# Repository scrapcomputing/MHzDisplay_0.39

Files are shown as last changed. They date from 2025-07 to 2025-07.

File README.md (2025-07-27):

# A Turbo LED MHz Display with 0.39" sized digits

A MHz Turbo LED display with 2x smaller 0.39" digits (12.8mm x 9.7mm x 7.0mm common cathode like the HD1107G).
These are smaller than the more common 0.56" display like the [TD-37S](https://github.com/scrapcomputing/MHzDisplayBlaster) or the [K568](https://github.com/scrapcomputing/MHzDisplay_K568).

I don't know the model number of the display that this is compatible with. If you do know please let me know!

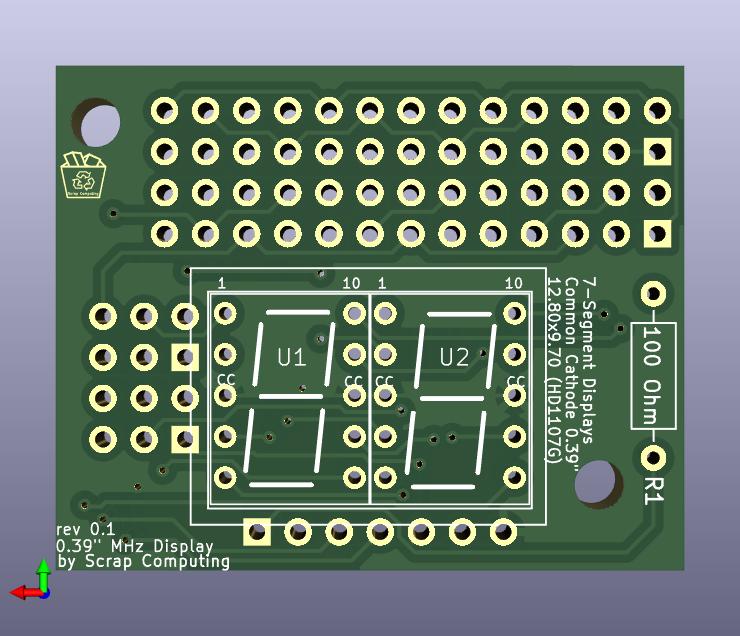
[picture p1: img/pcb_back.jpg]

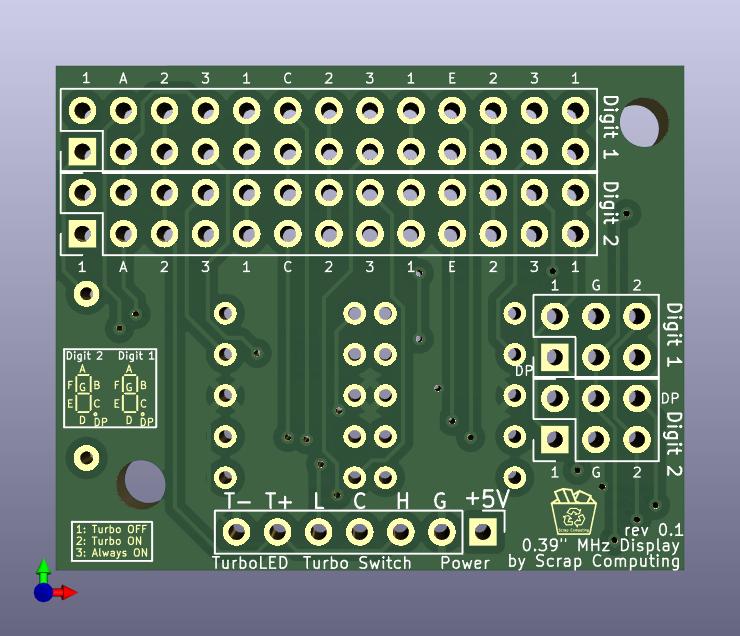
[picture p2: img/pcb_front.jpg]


As all similar displays, it is powered by 5V DC (pins +5V, G) and it can display a Turbo and a non-Turbo number, depending on the state of the Turbo switch (pins L C H, Low Common High).
It also drives the Turbo LED accordingly (pins T- and T+).

My case did not have an LED display that I could clone, so this is a design based on other common displays, like the [TD-37S](https://github.com/scrapcomputing/MHzDisplayBlaster).

Because of the limited space between the mounting holes, I had to the split the segment selection headers into two parts. The smaller headers are for segment G and the dot (DP).

# BOM

Gerber files are published in the [releases](https://github.com/scrapcomputing/MHzDisplay_0.39/releases).

Quantity | Item
---------|-------------------------------
2        | 2x13 2.54mm pitch pin headers
2        | 2x3  2.54mm pitch pin headers
1        | 1x7  2.54mm pitch pin header
1        | 100 Ohm 1/4 watt resistor (or smaller value for brighter display)
2        | Single-digit 7-segment Common-Cathode 0.39" displays that fit the PCB (display dimensions 9.7mm x 12.8mm x 7.0mm), like the HD1107G.
1        | [PCB](https://github.com/scrapcomputing/MHzDisplay_0.39/releases)

# Schematic



# Photos

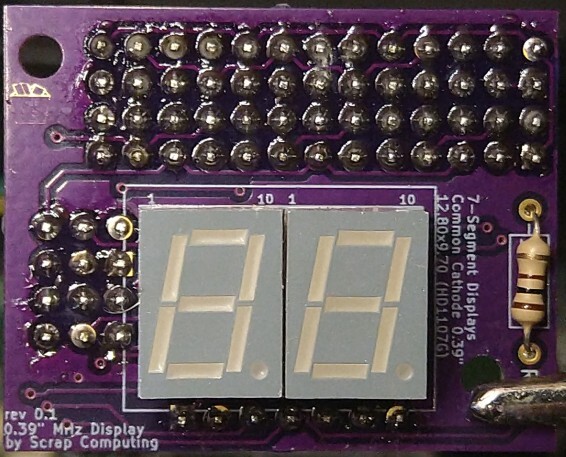
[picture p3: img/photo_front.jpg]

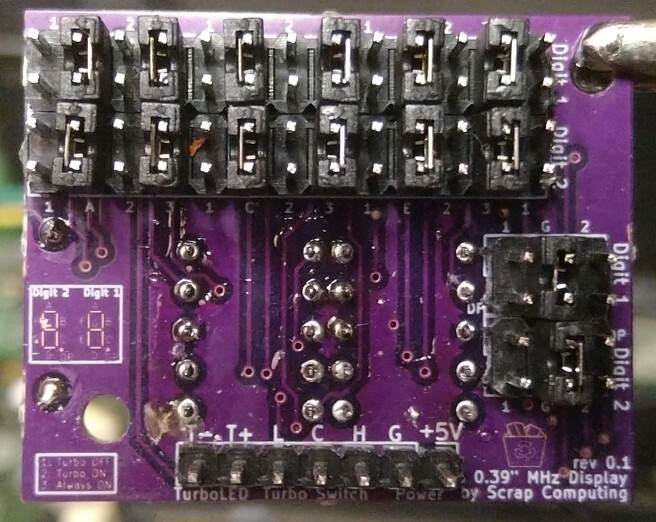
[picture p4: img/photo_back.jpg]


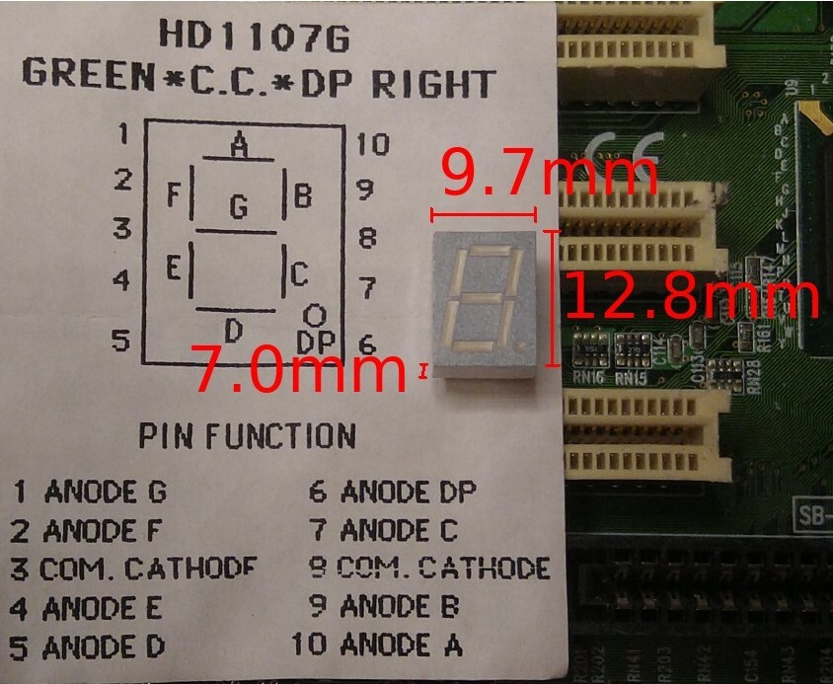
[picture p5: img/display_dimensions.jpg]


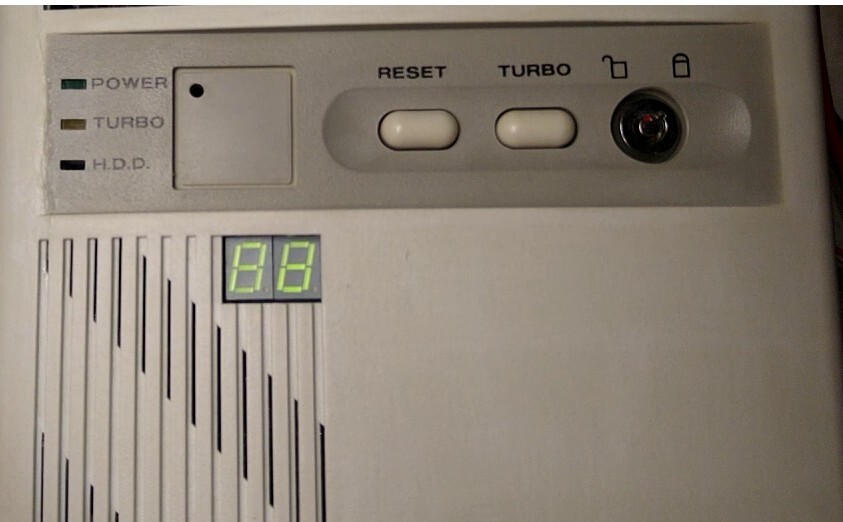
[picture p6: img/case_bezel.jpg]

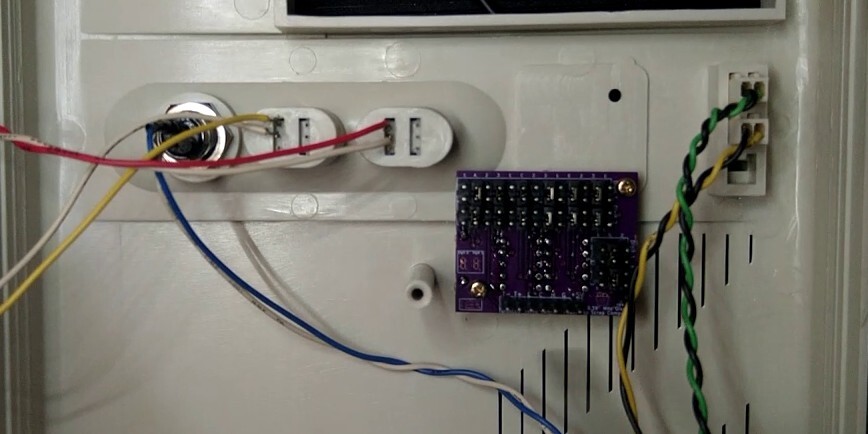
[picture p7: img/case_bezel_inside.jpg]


# Resources about MHz displays

- The best resource for MHz displays: [minuszerodegrees.net](https://www.minuszerodegrees.net/led_speed_display/led_speed_display.htm). It includes photos and manuals for a large selection of displays.

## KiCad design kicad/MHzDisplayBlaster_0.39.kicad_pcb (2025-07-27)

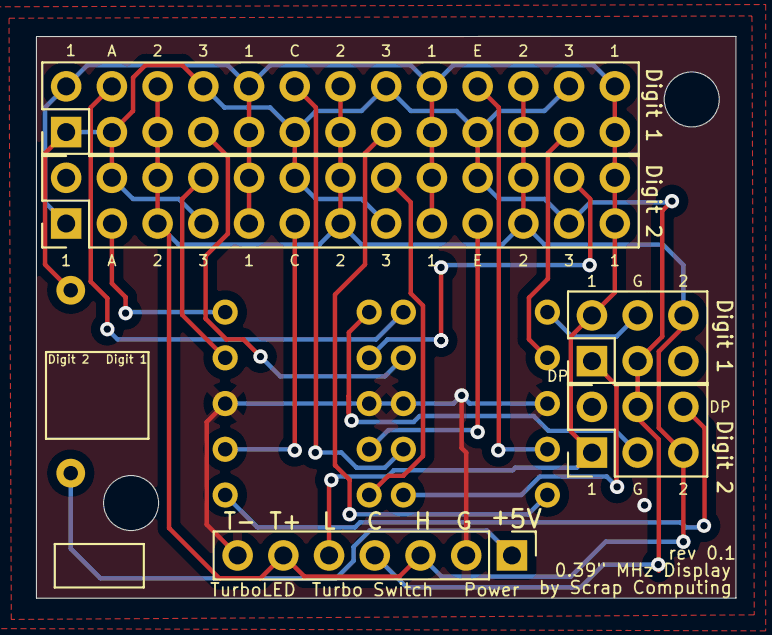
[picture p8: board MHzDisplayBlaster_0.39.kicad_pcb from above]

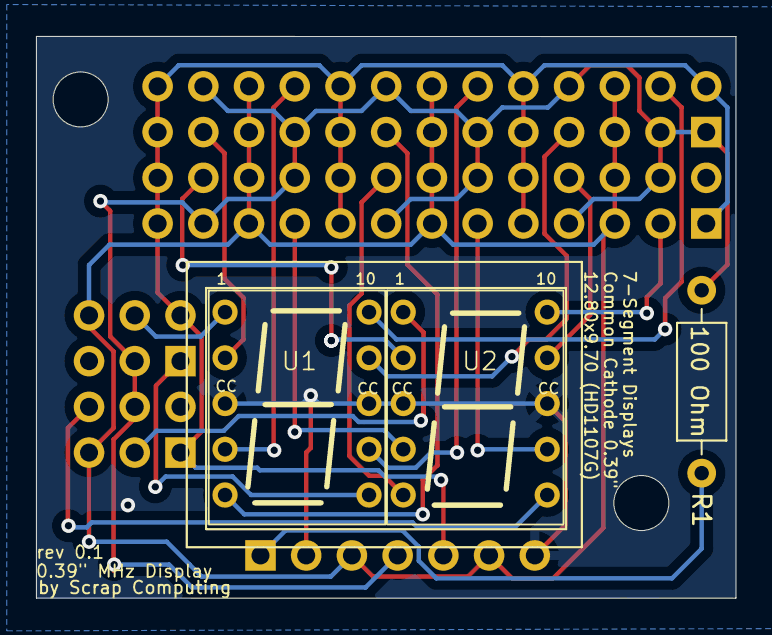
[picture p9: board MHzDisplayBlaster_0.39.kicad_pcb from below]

Board: 2 copper layers, 38.9 x 31.2 mm, 8 parts (3 on the bottom side), 21 nets.

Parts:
J1: Conn_02x13 DigitRHS; PinHeader_2x13_P2.54mm_Vertical
J2: Conn_02x14 DigitLHS; PinHeader_2x13_P2.54mm_Vertical
J3, J5: Conn_02x03_Odd_Even; PinHeader_2x03_P2.54mm_Vertical
J4: Conn_01x07; PinHeader_1x07_P2.54mm_Vertical
R1: 100 Ohm; R_Axial_DIN0207_L6.3mm_D2.5mm_P10.16mm_Horizontal
U1, U2: SC39-11GWA; HD1107

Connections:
1: J1.1, J1.9, J1.10, J1.17, J1.18, J1.25, J1.26, J2.2, J2.9, J2.10, J2.17, J2.18, J2.25, J2.26, J3.2, J4.5, J5.1
2: J1.5, J1.6, J1.13, J1.14, J1.21, J1.22, J2.5, J2.6, J2.13, J2.14, J2.21, J2.22, J3.6, J4.3, J4.6, J5.5
3: J1.4, J1.7, J1.12, J1.15, J1.20, J1.23, J2.1, J2.3, J2.8, J2.11, J2.16, J2.19, J2.24, J3.3, J4.4, J5.4, R1.1
+5V: J4.1, R1.2
DIG1_A: J2.4, U1.10 (A)
DIG1_B: J2.7, U1.9 (B)
DIG1_C: J2.12, U1.7 (C)
DIG1_CC: J4.2, J4.7, U1.3 (CC), U1.8 (CC), U2.3 (CC), U2.8 (CC)
DIG1_D: J2.15, U1.5 (D)
DIG1_DP: J3.1, U1.6 (DP)
DIG1_E: J2.20, U1.4 (E)
DIG1_F: J2.23, U1.2 (F)
DIG1_G: J3.4, U1.1 (G)
DIG2_A: J1.3, U2.10 (A)
DIG2_B: J1.8, U2.9 (B)
DIG2_C: J1.11, U2.7 (C)
DIG2_D: J1.16, U2.5 (D)
DIG2_DP: J5.6, U2.6 (DP)
DIG2_E: J1.19, U2.4 (E)
DIG2_F: J1.24, U2.2 (F)
DIG2_G: J5.3, U2.1 (G)
